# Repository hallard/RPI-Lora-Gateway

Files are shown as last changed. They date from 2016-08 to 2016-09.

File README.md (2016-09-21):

Raspberry PI Lora Gateway/Node for RFM92/95/96/98/69HCW Modules
===============================================================

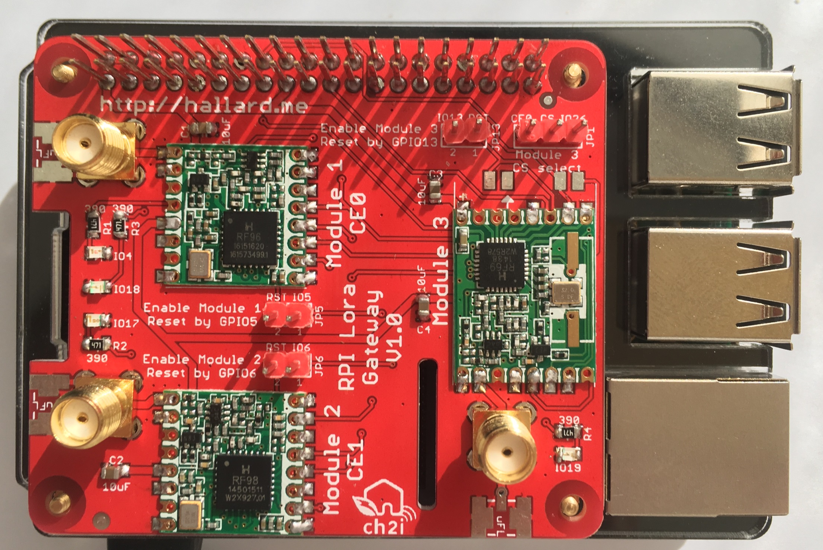
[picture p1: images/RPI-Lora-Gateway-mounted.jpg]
Raspberry PI Lora Gateway/Node
    

This shield is used to hold one or two HopeRF [Lora module][4] Software with Raspbery PI plus one FM12B/RFM69CW/RFM69(H)W.
it's the parent of the small [LoRasPi][11], so please look at LoRasPi [readme][12] to see features and software links.

This board has been mainly inspired from [Uptronics][14] expansion board on which I added some features but it's not a real LoraWAN concentrator, if you need a real concentrator with multiple channels and fully compliant to LoraWan stack capabilities, please see thethingsnetwork [wiki][1] dedicated to gateways.

By the way, with Lora modules installed on this board you can have it working as a Single Channel Gateway or a LoraWan node. For testing, demo or small projects, it can be enought.

Quick features 
==============

- Placement for two RFM92/95/96/98 Lora module (IE one 868MHz and one 433MHz, or 2 channels 868MHz)
- Placement for one RFM12B/RFM69CW/RFM69(H)W classic module
- Placement for choosing single Wire, SMA, u-FL or Thru Hole PCB Mount (Right Angle Tor straight)
by Eightwood Antenna type
- Vertical Antenna placement is possible (easier to drill RPI top enclosure)
- 4 x LED for visual indication
- Each Module reset pin can be connected to a RPI GPIO

Boards arrived from ElectroDragon, all is working as expected.

Detailed Description
====================

Look at the schematics for more informations.

SPI connexion is classic (MOSI/MISO/CLK), Chip Select is CE0 for Module 1 and CE1 for Module 2. Module 3 can be choosen between CE0 and GPIO26 with on board jumper switch.

```
Raspberry PI   RFM9x Module 1
   CE0     <---->  SEL
   GPIO5   <---->  Reset (JP5)
   GPIO25  <---->  DIO0 
   GPIO24  <---->  DIO5 

Raspberry PI   RFM9x Module 2
   CE1     <---->  SEL
   GPIO6   <---->  Reset (JP6)
   GPIO16  <---->  DIO0 
   GPIO12  <---->  DIO5 

Raspberry PI   RFM69/12 Module 3
 IO26/CE0  <---->  SEL
  GPIO13   <---->  Reset (JP13)
  GPIO23   <---->  DIO0 
  GPIO12   <---->  DIO2

Raspberry PI   On Board LEDS
   GPIO4   <---->  LED 4
   GPIO17  <---->  LED 17
   GPIO18  <---->  LED 18
   GPIO19  <---->  LED 19
```

### Hardware Setup

Nothing really complicated, you can wire Reset of each module on a GPIO pin if you want to be able to hardware reset then using software, in this case put jumper on JP5 for Module 1, JP6 for Module 2 and JP13 for Module 3. JPx number is the GPIO so JP5 is for GPIO5 ;-)

If you want to use Module 1 and Module 3 you need to set JP1 (Chip Select of module 3) to IO26 since CE0 is used by Module 1.

### Software Setup

I'm working on two libraries port and Single Channel Gateway to work on Raspberry PI, links are here   

- [LMIC][15] to be LoraWan compliant.  This LMIC is working with this shield, see [readme][18] of repo.
- Excellent [RadioHead][16] twekaed library for RFM69, RFM9x modules (and lot of others). This version is working with this shield, see [readme][17] of library.
- The Things Network [Single Channel Gateway packet forwarder][24]

I forked all repos to tweak them, but since I'm not sure original authors would like to merge my changes just use my forks. 

For reference, original libraries and code are [Arduino-LIMC][21], [RadioHead-LIMC][23], [Single Channel Gateway packet forwarder][25]

### Schematic  
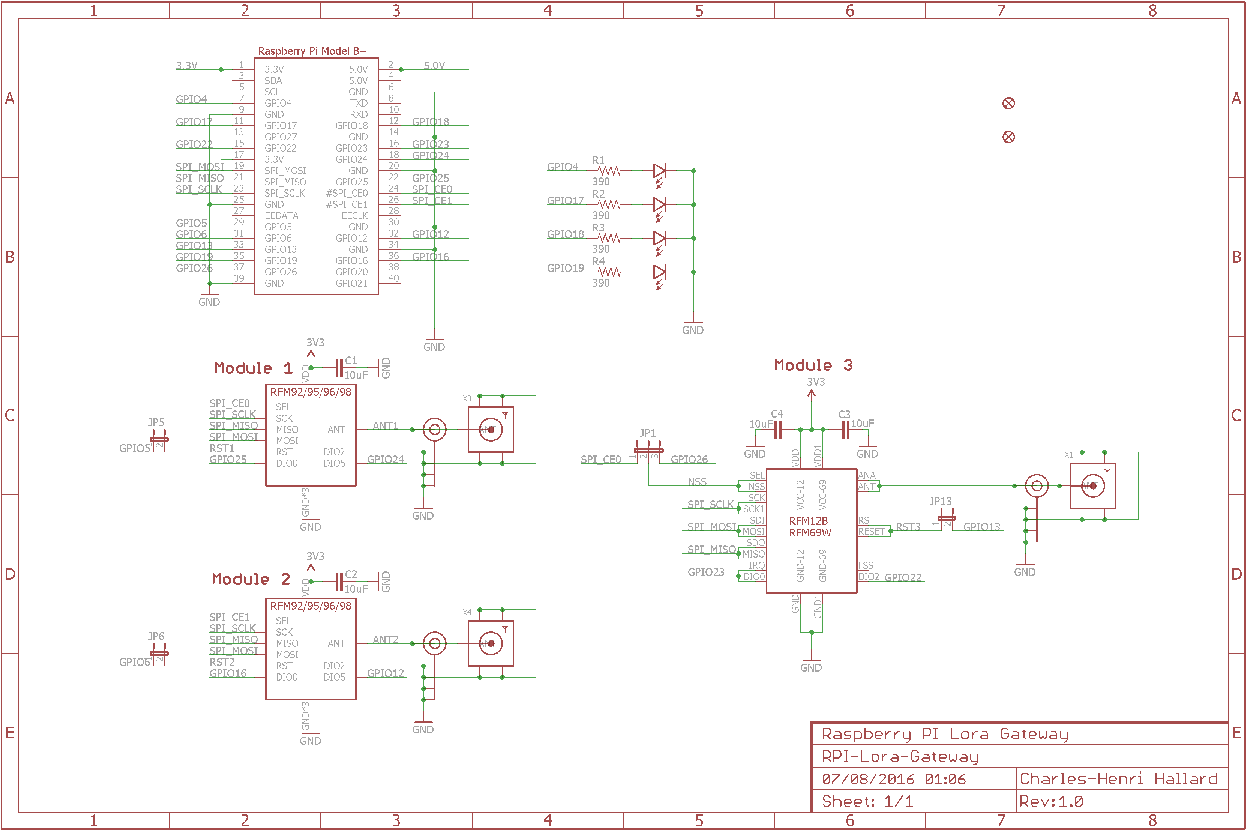
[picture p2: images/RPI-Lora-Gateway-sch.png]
schematic
  

### Boards  
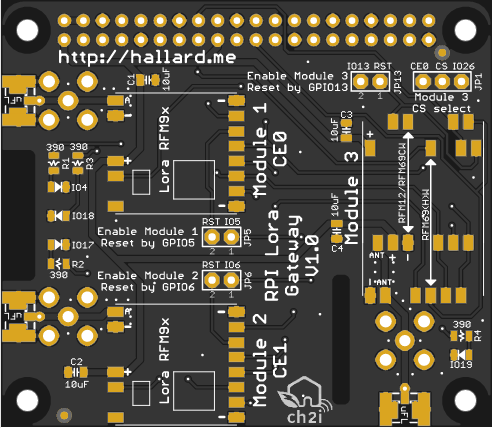
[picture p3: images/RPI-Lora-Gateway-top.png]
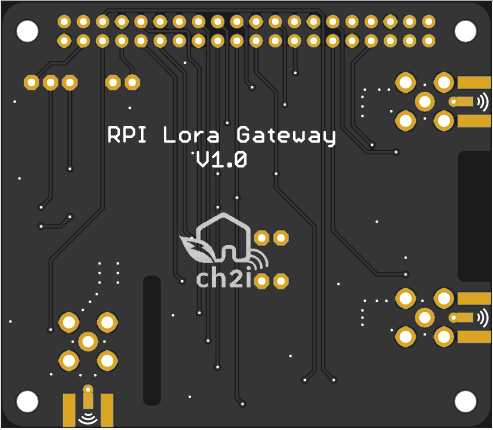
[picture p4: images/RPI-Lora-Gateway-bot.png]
&nbsp;&nbsp; 

### Received boards 

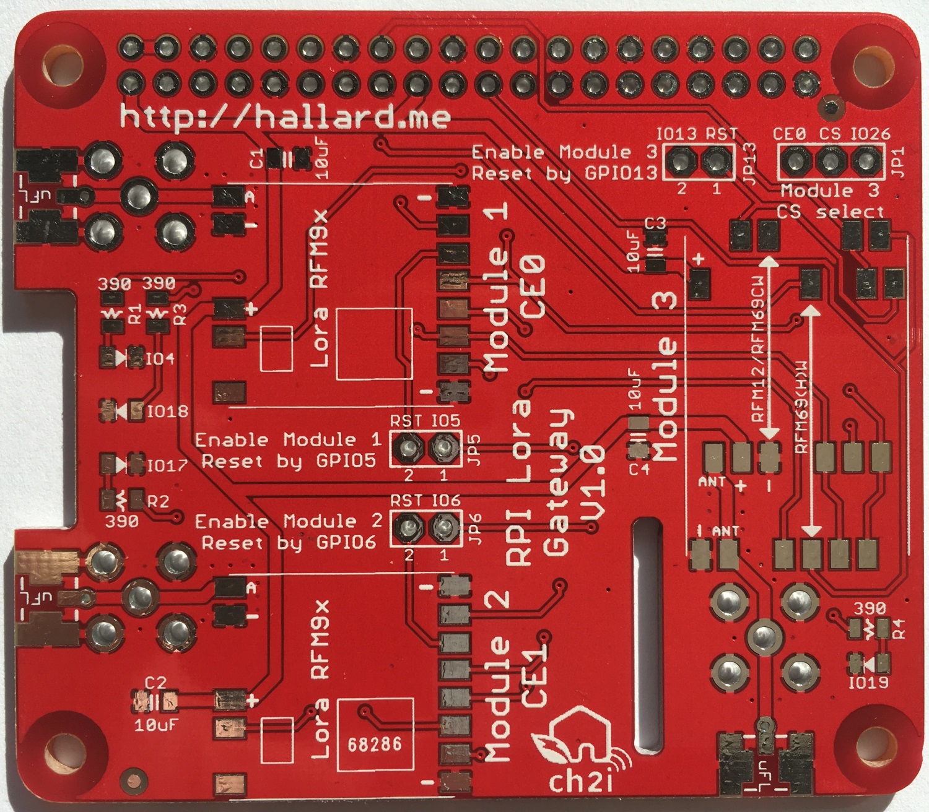
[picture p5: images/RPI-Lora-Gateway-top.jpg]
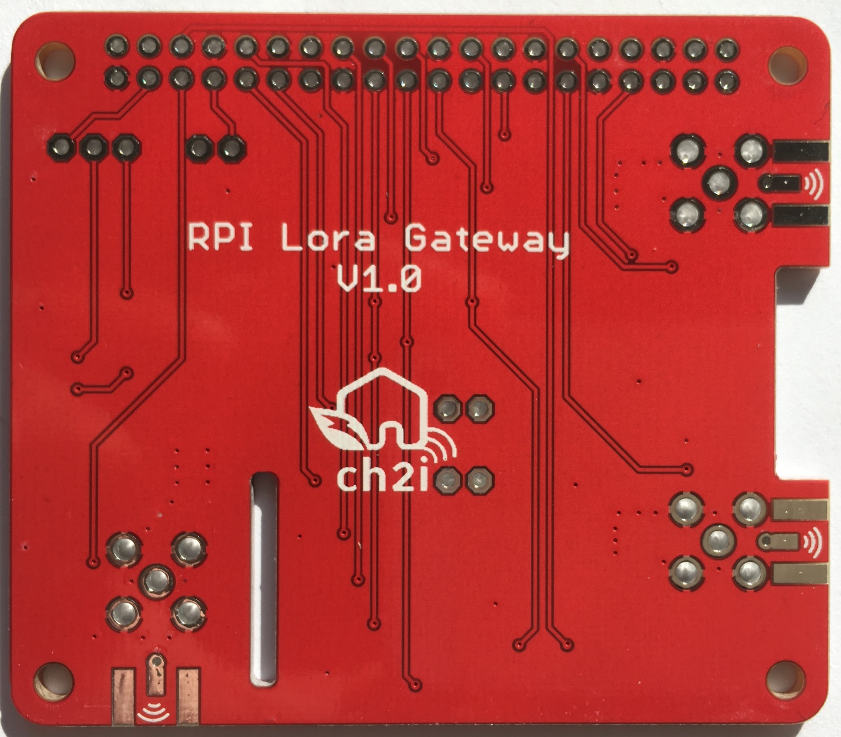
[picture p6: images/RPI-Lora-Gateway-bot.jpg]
&nbsp; 

You can order the PCB of this board [PCBs.io][13]. PCBs.io give me some reward when you order my designed boards from their site. This is pretty good, because I can use these rewards to create and design new boards and order boards for a discounted price and share new boards.

### Assembled and mounted board

Here is my testing board, as you can see, 3 modules on it    
- Module 1 (top left) Lora RFM95 868MHz
- Module 2 (bottom left) Lora RFM98 433MHz
- Module 3 (right) RFM69HW 433MHz

Mounted    

##License

You can do whatever you like with this design.

##Misc
See news and other projects on my [blog][2] 

[1]: https://www.thethingsnetwork.org/wiki/Hardware/Gateways/Overview
[2]: https://hallard.me
[4]: http://www.hoperf.com/rf_transceiver/lora/
[5]: https://github.com/hallard/single_chan_pkt_fwd
[6]: http://www.daveakerman.com/?p=1719
[7]: https://store.uputronics.com/index.php?route=product/product&search=lora&product_id=68
[8]: https://PCBs.io/share/zkD74
[9]: https://github.com/matthijskooijman/arduino-lmic/
[10]: https://github.com/hallard/RadioHead
[11]: https://github.com/hallard/LoRasPI
[12]: https://github.com/hallard/LoRasPI/blob/master/README.md
[13]: https://PCBs.io/share/zvxQ8
[14]: https://store.uputronics.com/index.php?route=product/product&search=lora&product_id=68

[15]: https://github.com/hallard/arduino-lmic/tree/rpi
[16]: https://github.com/hallard/RadioHead
[17]: https://github.com/hallard/RadioHead/blob/master/README.md
[18]: https://github.com/hallard/arduino-lmic/blob/rpi/README.md

[20]: https://github.com/hallard/arduino-lmic
[21]: https://github.com/matthijskooijman/arduino-lmic
[22]: https://github.com/hallard/RadioHead
[23]: http://www.airspayce.com/mikem/arduino/RadioHead/
[24]: https://github.com/hallard/single_chan_pkt_fwd
[25]: https://github.com/jlesech/single_chan_pkt_fwd

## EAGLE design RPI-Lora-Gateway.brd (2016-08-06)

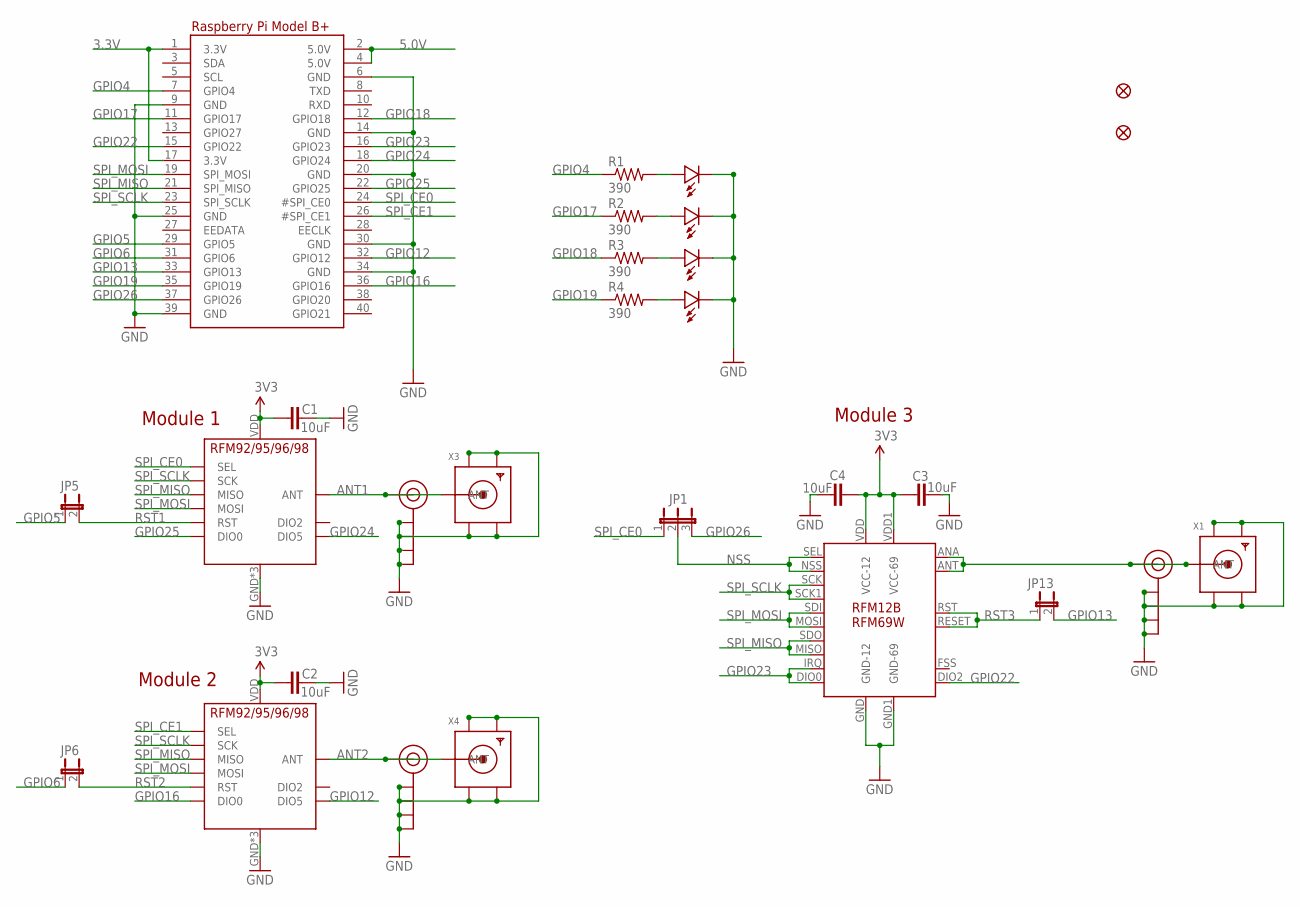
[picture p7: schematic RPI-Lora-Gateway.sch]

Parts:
C1, C2, C3, C4: 10uF; 0805-CAP
FID2, FID3: FIDUCIAL""; FIDUCIAL_1MM
J$1, J$2, J$3: ANTENNATINY; SMA_UFL_PAD_TINY
JP1: JUMPER3
JP5, JP6, JP13: JUMPER2
R1, R2, R3, R4: 390; 0805-RES
RPI1: RASPBERRYPI_BPLUS_HATNOSLOTS; PI_HAT_NOSLOTS
U$1, U$2: RFM95
U$3: RFM-DUAL
U$4: IO4; 0805-LED
U$5: IO17; 0805-LED
U$6: IO18; 0805-LED
U$7: IO19; 0805-LED
X1, X3, X4: SMACONNECTOR; SMA90_DIP

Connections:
3.3V: C1.1, C2.1, C3.1, C4.1, RPI1.1 (3.3V), RPI1.17 (3.3V), U$1.VDD (VCC), U$2.VDD (VCC), U$3.VDD (VCC-12), U$3.VDD1 (VCC-69)
5.0V: RPI1.2 (5.0V), RPI1.4 (5.0V)
ANT1: J$1.ANT1 (SIGNAL), J$1.ANT2 (SIGNAL), J$1.ANT3 (SIGNAL), U$1.ANT, X3.ANTENNA (ANT)
ANT2: J$2.ANT1 (SIGNAL), J$2.ANT2 (SIGNAL), J$2.ANT3 (SIGNAL), U$2.ANT, X4.ANTENNA (ANT)
GND: C1.2, C2.2, C3.2, C4.2, J$1.GND1 (GND), J$1.GND2 (GND), J$1.GND3 (GND), J$1.GND4 (GND), J$2.GND1 (GND), J$2.GND2 (GND), J$2.GND3 (GND), J$2.GND4 (GND), J$3.GND1 (GND), J$3.GND2 (GND), J$3.GND3 (GND), J$3.GND4 (GND), RPI1.6 (GND), RPI1.9 (GND), RPI1.14 (GND), RPI1.20 (GND), RPI1.25 (GND), RPI1.30 (GND), RPI1.34 (GND), RPI1.39 (GND), U$1.GND, U$1.GND1 (GND), U$1.GND2 (GND), U$2.GND, U$2.GND1 (GND), U$2.GND2 (GND), U$3.GND (GND-12), U$3.GND1 (GND-69), U$4.MINUS, U$5.MINUS, U$6.MINUS, U$7.MINUS, X1.GND1, X1.GND2, X1.GND3, X1.GND4, X3.GND1, X3.GND2, X3.GND3, X3.GND4, X4.GND1, X4.GND2, X4.GND3, X4.GND4
GPIO4: R1.1, RPI1.7 (GPIO4)
GPIO5: JP5.1, RPI1.29 (GPIO5)
GPIO6: JP6.1, RPI1.31 (GPIO6)
GPIO12: RPI1.32 (GPIO12), U$2.DIO5
GPIO13: JP13.2, RPI1.33 (GPIO13)
GPIO16: RPI1.36 (GPIO16), U$2.DIO0
GPIO17: R2.1, RPI1.11 (GPIO17)
GPIO18: R3.1, RPI1.12 (GPIO18)
GPIO19: R4.1, RPI1.35 (GPIO19)
GPIO22: RPI1.15 (GPIO22), U$3.DIO2
GPIO23: RPI1.16 (GPIO23), U$3.DIO0, U$3.IRQ
GPIO24: RPI1.18 (GPIO24), U$1.DIO5
GPIO25: RPI1.22 (GPIO25), U$1.DIO0
GPIO26: JP1.3, RPI1.37 (GPIO26)
unnamed: J$3.ANT1 (SIGNAL), J$3.ANT2 (SIGNAL), J$3.ANT3 (SIGNAL), U$3.ANA (ANT-12), U$3.ANT (ANT-69), X1.ANTENNA (ANT)
unnamed: R4.2, U$7.PLUS
unnamed: R1.2, U$4.PLUS
unnamed: R2.2, U$5.PLUS
unnamed: R3.2, U$6.PLUS
NSS: JP1.2, U$3.NSS (SEL-12), U$3.SEL (SEL-69)
RST1: JP5.2, U$1.RST
RST2: JP6.2, U$2.RST
RST3: JP13.1, U$3.RESET, U$3.RST
SPI_CE0: JP1.1, RPI1.24 (#SPI_CE0), U$1.NSS (SEL)
SPI_CE1: RPI1.26 (#SPI_CE1), U$2.NSS (SEL)
SPI_MISO: RPI1.21 (SPI_MISO), U$1.MISO, U$2.MISO, U$3.MISO, U$3.SDO
SPI_MOSI: RPI1.19 (SPI_MOSI), U$1.MOSI, U$2.MOSI, U$3.MOSI, U$3.SDI
SPI_SCLK: RPI1.23 (SPI_SCLK), U$1.SCK, U$2.SCK, U$3.SCK, U$3.SCK1

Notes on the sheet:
Module 1
Module 2
Module 3

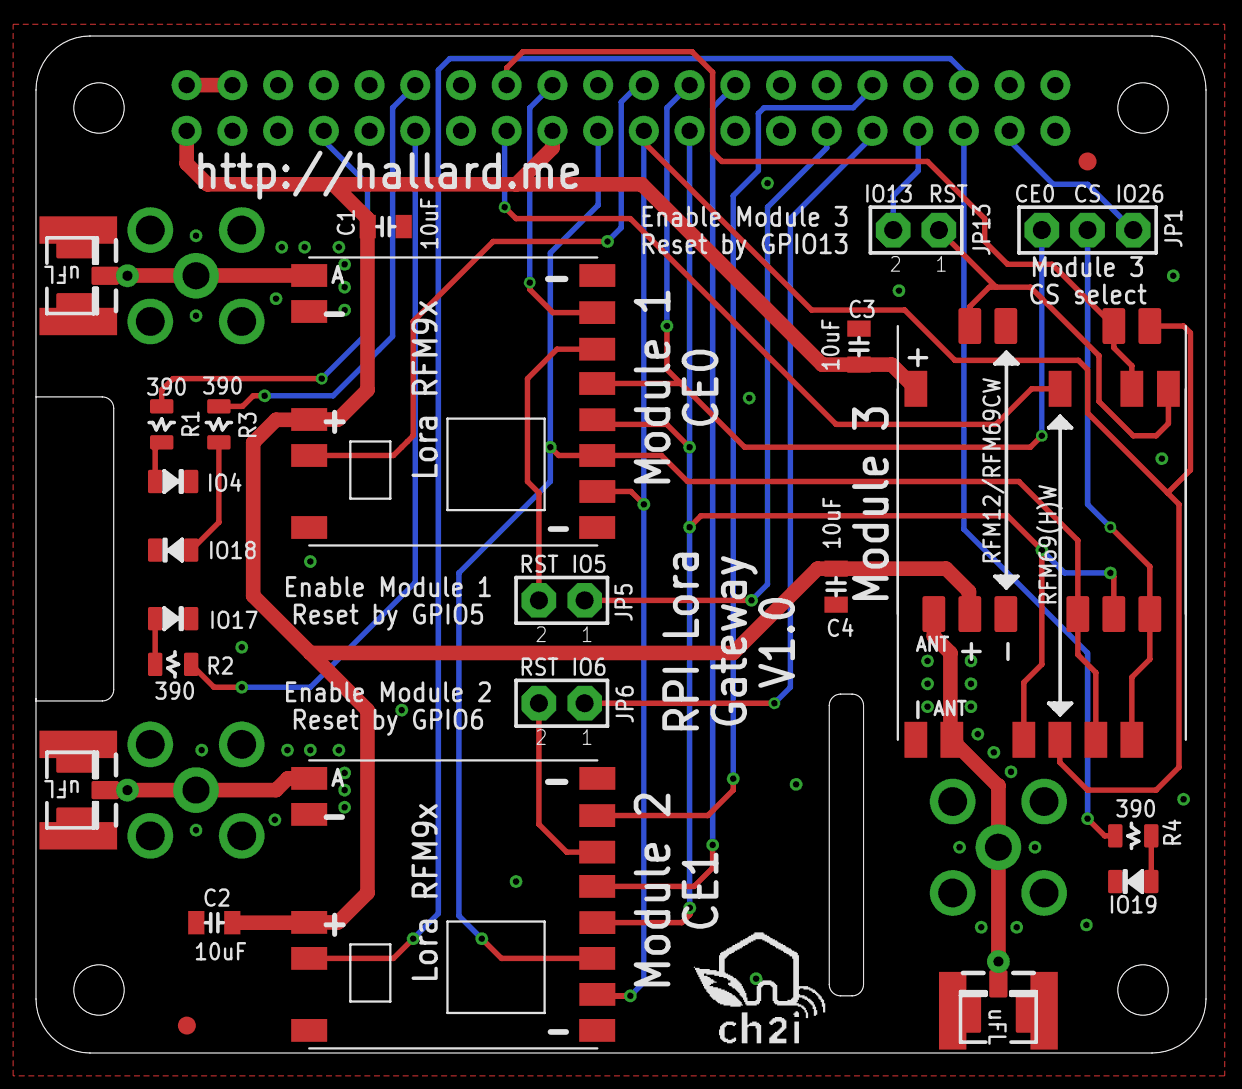
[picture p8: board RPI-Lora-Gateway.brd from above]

Board: 2 copper layers, 65.0 x 56.5 mm, 30 parts (1 on the bottom side), 33 nets.

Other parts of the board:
U$8: LOGO_CH2I_75MM
U$9: LOGO_CH2I_110MM

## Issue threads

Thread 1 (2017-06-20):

Configuration for single_channel_pkt_forwarder?

mvdswaluw, 2017-06-20:
Hello,

in the README,md there is a reference to the single_chan_pkt_fwd-page. On that [link](https://github.com/hallard/single_chan_pkt_fwd/blob/master/README.md) you cannot find how to configure this RPI-Lora-Gateway. I've tried to find it out myself, but was not successful. I use a RFM95 on the position of module1 and RFM69HW on the postiion of module 3. I would at least like a example config to  get the RFM95 to work on position 1&2.

hallard, 2017-06-23:
The link should give you access to this software, Are you using this one ?
https://github.com/hallard/single_chan_pkt_fwd
if it's the case then (Wiring Numbering)
RFM95 on positon 1 is
```
  "pin_nss": 10, // CE0
  "pin_dio0": 6, // GPIO25
  "pin_rst": 21, // GPIO21
  "pin_led1":7 // GPIO7
```
RFM95 on positon 2 is
```
  "pin_nss": 11, // CE1
  "pin_dio0": 27, // GPIO27
  "pin_rst": 22, // GPIO22
  "pin_led1":0 // GPIO0
```
Hope this help

iBrick, 2018-12-20:
Hi Hallard, should I run 2 instances of single_channel_pkt_forwarder to get 2 boards working?

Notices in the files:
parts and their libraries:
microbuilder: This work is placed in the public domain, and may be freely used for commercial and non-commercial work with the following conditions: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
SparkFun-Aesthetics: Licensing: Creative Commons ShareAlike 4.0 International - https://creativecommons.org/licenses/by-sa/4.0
